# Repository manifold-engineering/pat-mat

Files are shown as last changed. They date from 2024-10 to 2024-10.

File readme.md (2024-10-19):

# Pat-Mat
**Phantom And Tonader - Microphone Adapter Thing**

World of professional audio has moved to phantom power for condenser microphones decades ago. But there are good microphones from older days out that used other standards - most notably tonader power (also called T12, T-Power or AB power). Pat-Mat (Phantom And Tonader - Microphone Adapter Thing) is a professional-grade adapter designed to convert standard 48V phantom power into 12V tonader power.

Pat-Mat consists of single PCB designed to fit inside standard XLR male connector (output connctor, like Neutrik NC3MXX series), allows for fit for standard cable relief. Users may choose cable and microphone connector for their specific microphones (DIN, Tuchel...).

## Hardware design

Hardware design is meant be as simple as possible.

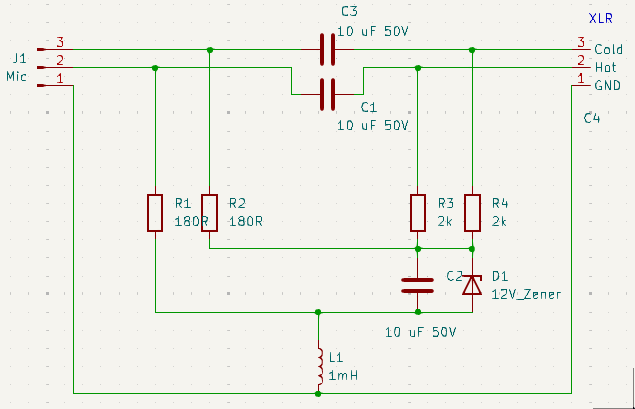
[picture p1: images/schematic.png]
schematics


12V is prepared by voltage divider resistors (R3, R4) to Zener diode. Audio signal is by connected through C1 and C3 capacitors.

All schematics and PCB design files are available in the `/pat-mat-pcb` directory in KiCAD 8 format. There is output folder with gerber file outputs for manufacturing. They were successfully manufactured by JLC-PCB. Simple BOM file with links to TME is provided. Since Pat-Mat design is simple and only need standard components, it should be possible to source parts from your favourite supplier.

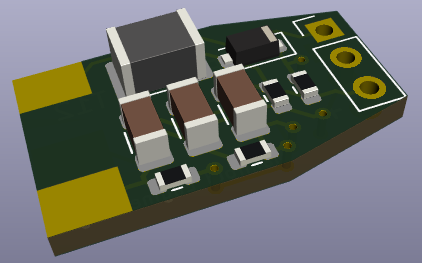
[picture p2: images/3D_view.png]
3D view


**In order to fit to standard XLR connector, order you PCB 1.2 mm thick. 1.6 mm wont fit!**

## Assembly

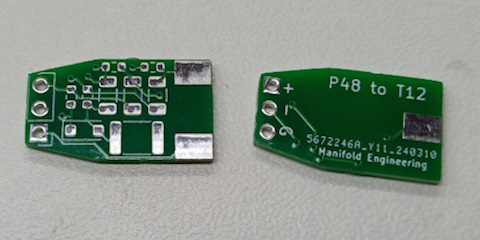
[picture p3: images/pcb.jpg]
bare PCB


*(note: This is development version, + and G pins are flipped. It is fixed in published version.)*

First populate SMD components onto PCB (or preferably order assmebled PCBs)

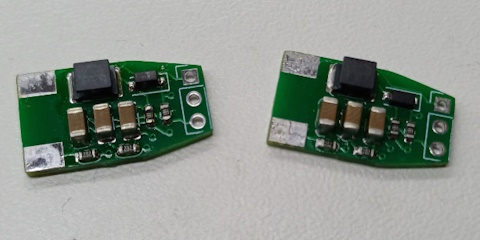
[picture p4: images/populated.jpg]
populated PCB


Then solder PCB into XLR pins

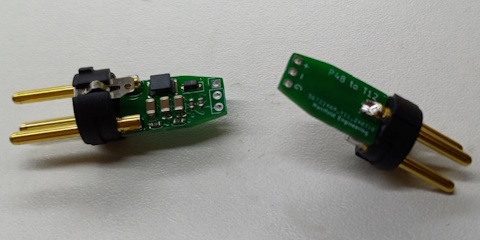
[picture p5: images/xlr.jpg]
PCB in XLR


Then add cable of your choice. You mich have to trim some strands of shielding to fit into PCB. You might have to let shorter loose wires than you would do whe soldering standard connector.

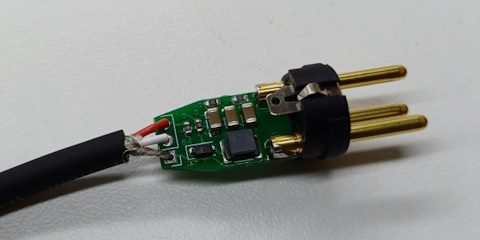
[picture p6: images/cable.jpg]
PCB in XLR with cable


Add cable relief

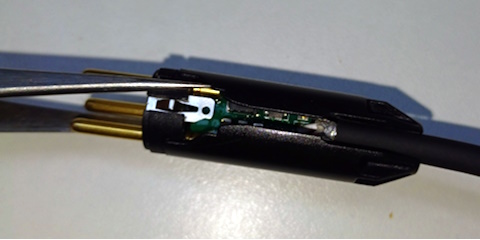
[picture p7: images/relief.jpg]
PCB in XLR with cable relief


And finish cable like you would the standard way. 

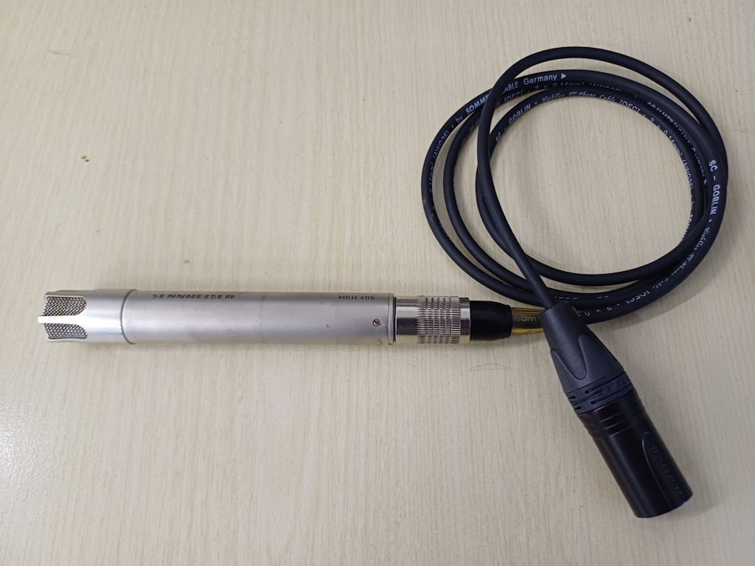
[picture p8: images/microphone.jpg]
finisher adapter with microphone


## License

This project is open-source under the MIT License—feel free to use, modify, and improve Pat-Mat for your own audio needs.

---

**"A Je To!"**

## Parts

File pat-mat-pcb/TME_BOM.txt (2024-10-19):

L:	1x	1812	https://www.tme.eu/cz/details/b82432t1105k000/tlumivky-smd-1812/epcos/
C:	3x	1206	https://www.tme.eu/cz/details/12065d106kat2a/kondenzatory-mlcc-smd/kyocera-avx/
ZD:	1x	SOD123	https://www.tme.eu/cz/details/mmsz5242b-dio/zenerovy-diody-smd/diotec-semiconductor/mmsz5242b/
R:	2x	0603	https://www.tme.eu/cz/details/smd0603-2k-1%25/rezistory-smd/royalohm/0603saf2001t5e/	
R:	2x	0603	https://www.tme.eu/cz/details/smd0603-180r-1%25/rezistory-smd/royalohm/0603saf1800t5e/

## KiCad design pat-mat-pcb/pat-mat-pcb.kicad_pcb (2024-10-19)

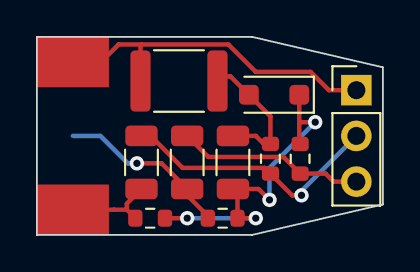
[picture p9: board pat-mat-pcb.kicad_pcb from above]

Board: 2 copper layers, 19.2 x 11.0 mm, 11 parts (0 on the bottom side), 7 nets.

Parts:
C1, C2, C3: C; C_1206_3216Metric
C4: XLR_PCB
D1: 12V_Zener; D_SOD-123F
J1: Conn_01x03_Pin; PinHeader_1x03_P2.54mm_Vertical
L1: 1mH; L_1812_4532Metric
R1, R2: 180R; R_0603_1608Metric
R3, R4: 680R; R_0603_1608Metric

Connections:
unnamed: C3.2, C4.3 (Cold), R4.1
unnamed: C4.1 (GND), J1.1, L1.2
unnamed: C1.2, C4.2 (Hot), R3.1
unnamed: C2.2, D1.2 (A), L1.1, R1.2
unnamed: C2.1, D1.1 (K), R2.2, R3.2, R4.2
unnamed: C1.1, J1.2, R1.1
unnamed: C3.1, J1.3, R2.1
